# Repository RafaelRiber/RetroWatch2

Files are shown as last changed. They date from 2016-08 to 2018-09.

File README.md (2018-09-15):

# Retro|Watch 2
 <p align="center">
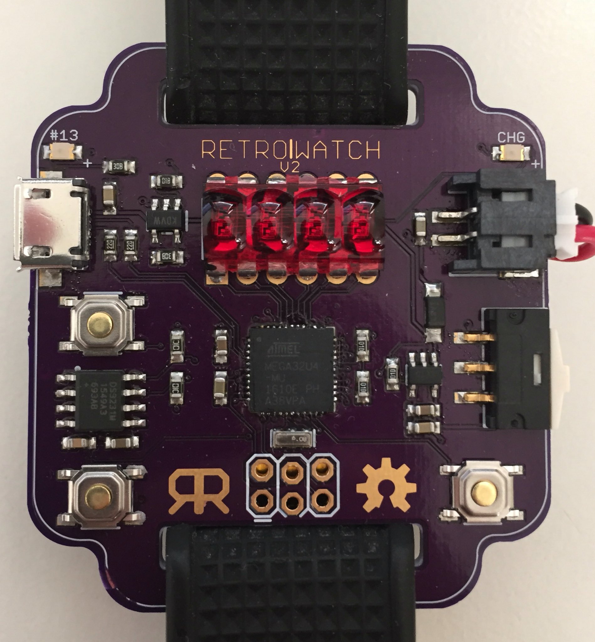
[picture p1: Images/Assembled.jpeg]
 
 <em>Assembled Board</em>
 
## Short description
The Retro|Watch V2 is based around the HP QDSP-6064 Bubble display, used in 70s HP calculators like the [HP-35](https://en.wikipedia.org/wiki/HP-35). The display is controlled by an Atmel ATMega328U4 MCU with Arduino code and flashed with an Adafruit Feather 32U4 bootloader, and the time is kept by a Maxim DS3231 Real-Time Clock module, that stays connected to the LiPo battery at all times, keeping time even when the microcontroller and display are not powered.
This second version of the watch uses another microcontroller, the ATMega32U4, for USB capability, and a battery recharge circuit for USB Charging. In order to fit all that added circuitry, smaller components as 0603 resistors and a QFN chip were used. **__THIS MAKES ASSEMBLY CONSIDERABLY HARDER THAN V1, and is not recommended for beginners.__**
The code is open source, licensed under the MIT License, and the harware is open-source hardware.

<h3>V1 was Featured on:</h3>
<p><a href="http://hackaday.com/2016/06/25/easy-bubble-watch-oozes-retro-charm/">Hackaday.com blog post by Elliot Williams</a>
<p><a href="https://blog.hackster.io/this-watch-will-spark-some-old-school-calculator-nostalgia-7b6e44203b67">Hackster.io</a>
  
## Hardware
<h3>PCB</h3>
The board design was made in Eagle, and is fully tested. A 500 mAh [LiPo Battery from Adafruit](https://adafru.it/1578) fits perfectly under the board. The board design can be freely modified. It can also directly be ordered on the OSHPark website: 
<p align="center"></p>

<h3>Bill Of Materials</h3>
You can find the BOM here: https://github.com/RafaelRiber/Retro-Watch2/blob/master/Hardware/BOM.csv
  
<h2>Software</h2>
The software was written in Arduino code, is licensed under MIT License, and can be uploaded on the microcontroller via ISP.
Be sure to set the desired time in the code prior to uploading, to set the time registers on the RTC.

Functions of the code include:
* Hours, minutes and seconds
* Day, month, year, day of year, day in week, week in year.
* Stopwatch (start, stop, reset)
* Brightness setting in software, saved to EEPROM to save even if the watch is powered off.
* Battery voltage check and low battery alert
 
To be able to upload the code on the watch, you will need to follow the same steps as V1 (see V1 repo), but using the Adafruit Feather 32U4 Bootloader instead of the ATMega328P one.
<h3>Required Libraries</h3>
<p>1. Chrono library by thomasfredericks: https://github.com/thomasfredericks/Chrono
<p>2. Button library by JChristensen: https://github.com/JChristensen/Button
<p>3. RTCLib by Adafruit Industries: https://github.com/adafruit/RTClib
<p>4. SevSeg by SparkFun: https://github.com/sparkfun/SevSeg

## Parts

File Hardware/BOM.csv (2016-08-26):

Qty | Value | Device | Package | Parts
1 | 0.1uF | C0603 | C0603 | C7
3 | 100K | R0603 | R0603 | R1 R7 R8
2 | 10K | R0603 | R0603 | R11 R12
4 | 10uF | C0603 | C0603 | C1 C2 C4 C6
1 | 1K | R0603 | R0603 | R2
3 | 1uF | C0603 | C0603 | C3 C5 C8
2 | 22R | R0603 | R0603 | R3 R4
2 | 2K | R0603 | R0603 | R5 R6
1 | 8MHz | RESONATOR SMD | RESONATOR-SMD | Y1
1 | ATMEGA32U4-MU | MCU | QFN-44 | U1
1 | DS3231M | RTC | SOIC8 | RTC1
1 | MBR120 | Schottky Diode | SOD-123 | D1
1 | MCP73831T-2ACI/OT | LiPoly Charger | SOT23-5 | U2
1 | MCS2S-A15F | SPDT Slide Switch | MCS2S-A15F | S1
1 | MIC5225-3.3YM5-TR | Voltage Regulator 3.3V | SOT23-5 | U3
1 | 10104110-0001LF | USB Connector | USB-MICROB-SMD | X2

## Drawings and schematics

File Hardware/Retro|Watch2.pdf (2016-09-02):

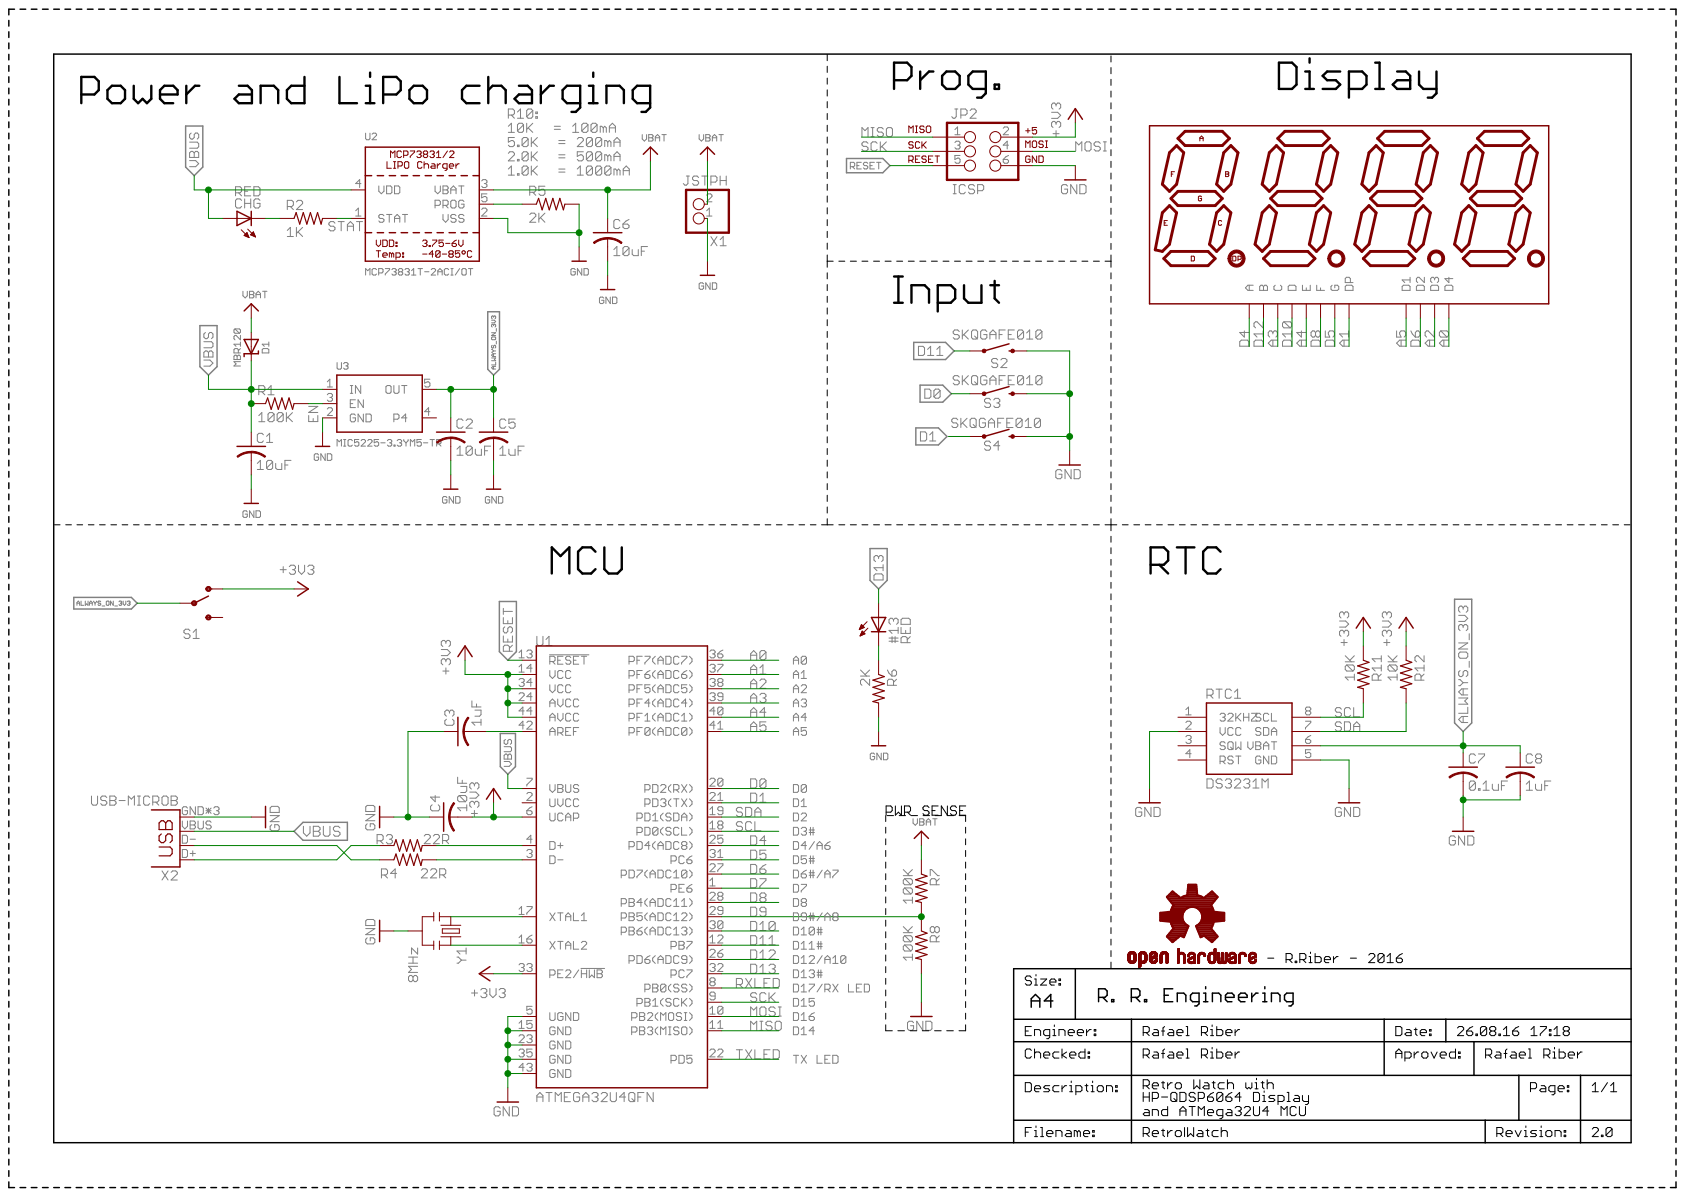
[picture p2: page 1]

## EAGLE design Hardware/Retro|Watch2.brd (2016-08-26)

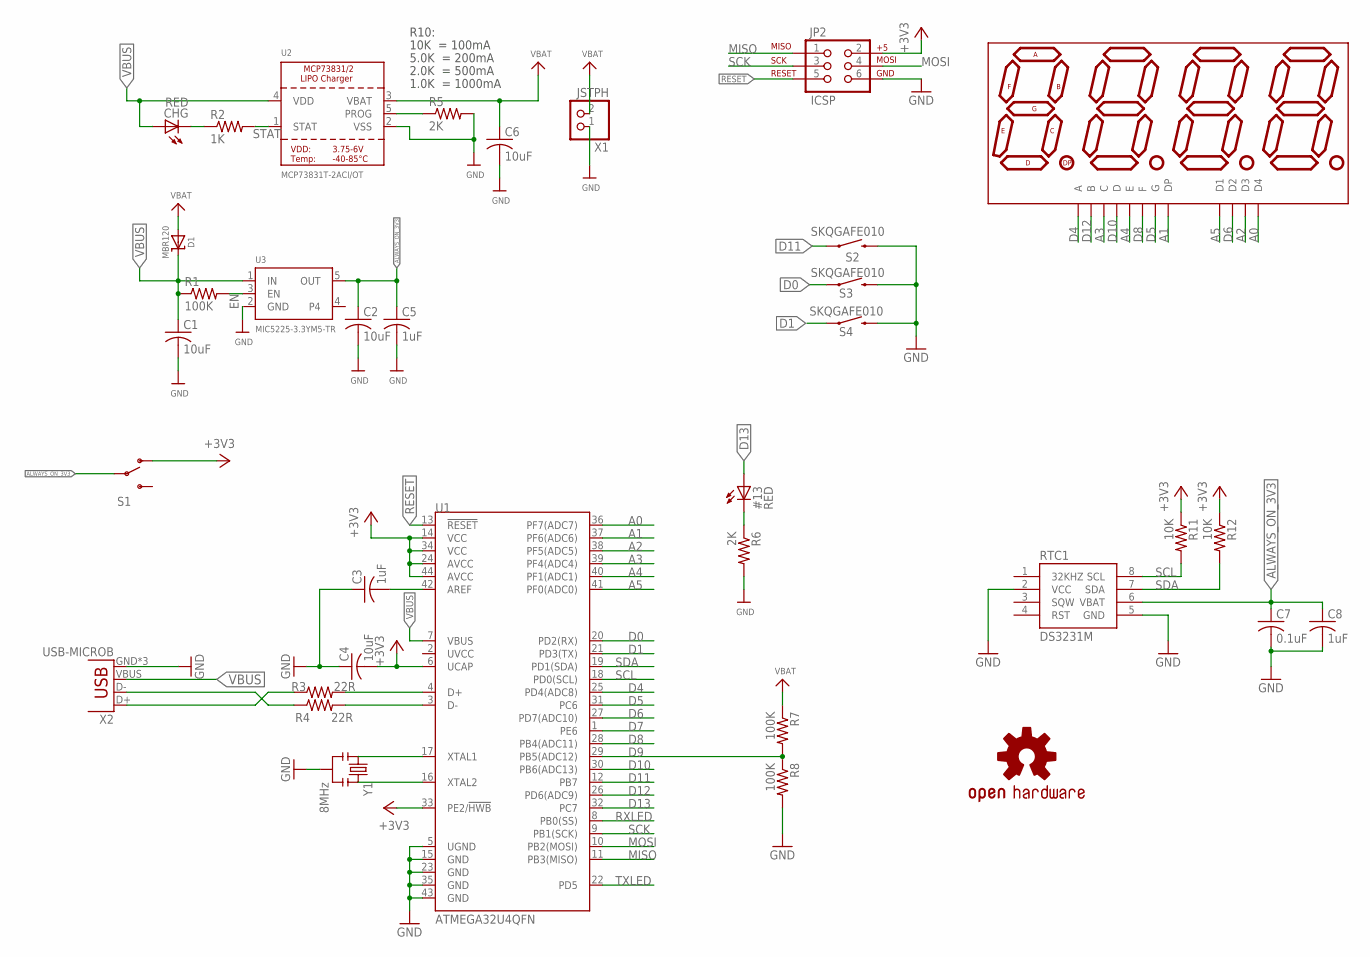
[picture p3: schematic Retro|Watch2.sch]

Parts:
#13: RED; CHIP-LED0805; MPN LGQ971
C1, C2, C6: 10uF; C0603; MPN MC0603X106M6R3CT
C3: 1uF; C0603; MPN 0805B104K500CT
C4: 10uF; C0603; MPN 0805B104K500CT
C5: 1uF; C0603; MPN CC0603MRY5V9BB104
C7: 0.1uF; C0603; MPN 0805B104K500CT
C8: 1uF; C0603; MPN 0603X105K100CT
CHG: RED; CHIP-LED0805; MPN LSQ976-Z
D1: MBR120; SOD-123; MPN MBR120VLSFT1G
DISP1: hp; DIL12
JP2: ICSP; 2X3_LOCK
LOGO1: OSHW-LOGOM-COPPER; OSHW-LOGO-M_COPPER
R1, R7, R8: 100K; R0603; MPN CRCW0603100KFKEA.
R2: 1K; R0603; MPN MC0063W06031221R
R3, R4: 22R; R0603; MPN CRCW060322R0FKEA
R5: 2K; R0603; MPN CRCW060310K0JNEA
R6: 2K; R0603; MPN CRCW06032K20JNEA
R11, R12: 10K; R0603; MPN CRCW060310K0FKEA
RTC1: DS3231M; SOIC8; MPN DS3231MZ+TRL
S1: SWITCH-SPDTSMD2; SWITCH-SPDT-SMD
S2, S3, S4: SKQGAFE010; TACTILE-SWITCH-SMD; MPN SKQGAFE010
U1: ATMEGA32U4QFN; QFN-44; MPN ATMEGA32U4-MU
U2: MCP73831T-2ACI/OT; SOT23-5@1; MPN MCP73831T-2ACI/OT
U3: MIC5225-3.3YM5-TR; SOT23-5; MPN MIC5225-3.3YM5-TR
X1: JSTPH; JSTPH2; MPN S2B-PH-SM4-TB(LF)(SN)
X2: USB-MICROB; MPN 10104110-0001LF
Y1: 8MHz; RESONATOR-SMD

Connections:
+3V3: C4.2, JP2.2, R11.1, R12.1, S1.1 (O), U1.6 (UCAP), U1.14 (VCC), U1.24 (AVCC), U1.33 (PE2/!HWB), U1.34 (VCC), U1.44 (AVCC)
A0: DISP1.6 (D4), U1.36 (PF7(ADC7))
A1: DISP1.5 (DP), U1.37 (PF6(ADC6))
A2: DISP1.4 (D3), U1.38 (PF5(ADC5))
A3: DISP1.3 (C), U1.39 (PF4(ADC4))
A4: DISP1.2 (E), U1.40 (PF1(ADC1))
A5: DISP1.1 (D1), U1.41 (PF0(ADC0))
ALWAYS_ON_3V3: C2.1, C5.1, C7.1, C8.1, RTC1.6 (VBAT), S1.2, U3.5 (OUT)
AREF: C3.2, U1.42 (AREF)
D0: S3.1, U1.20 (PD2(RX))
D1: S4.1, U1.21 (PD3(TX))
D4: DISP1.12 (A), U1.25 (PD4(ADC8))
D5: DISP1.7 (G), U1.31 (PC6)
D6: DISP1.10 (D2), U1.27 (PD7(ADC10))
D7: U1.1 (PE6)
D8: DISP1.9 (F), U1.28 (PB4(ADC11))
D9: R7.2, R8.1, U1.29 (PB5(ADC12))
D10: DISP1.8 (D), U1.30 (PB6(ADC13))
D11: S2.1, U1.12 (PB7)
D12: DISP1.11 (B), U1.26 (PD6(ADC9))
D13: #13.A, U1.32 (PC7)
D+: R3.1, X2.D+
D-: R4.1, X2.D-
EN: R1.2, U3.3 (EN)
GND: C1.2, C2.2, C3.1, C4.1, C5.2, C6.2, C7.2, C8.2, JP2.6, R5.2, R6.2, R8.2, RTC1.2 (VCC), RTC1.5 (GND), S2.3 (2), S3.3 (2), S4.3 (2), U1.5 (UGND), U1.15 (GND), U1.23 (GND), U1.35 (GND), U1.43 (GND), U2.2 (VSS), U3.2 (GND), X1.1, X2.GND, X2.MT1 (GND), X2.MT2 (GND), Y1.2
MISO: JP2.1, U1.11 (PB3(MISO))
MOSI: JP2.4, U1.10 (PB2(MOSI))
unnamed: U1.17 (XTAL1), Y1.1
unnamed: U1.16 (XTAL2), Y1.3
unnamed: R3.2, U1.4 (D+)
unnamed: R4.2, U1.3 (D-)
unnamed: CHG.C, R2.1
unnamed: #13.C, R6.1
PROG: R5.1, U2.5 (PROG)
RESET: JP2.5, U1.13 (!RESET)
RXLED: U1.8 (PB0(SS))
SCK: JP2.3, U1.9 (PB1(SCK))
SCL: R11.2, RTC1.8 (SCL), U1.18 (PD0(SCL))
SDA: R12.2, RTC1.7 (SDA), U1.19 (PD1(SDA))
STAT: R2.2, U2.1 (STAT)
TXLED: U1.22 (PD5)
VBAT: C6.1, D1.A, R7.1, U2.3 (VBAT), X1.2
VBUS: C1.1, CHG.A, D1.C, R1.1, U1.7 (VBUS), U2.4 (VDD), U3.1 (IN), X2.VBUS

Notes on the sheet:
10K = 100mA
5.0K = 200mA
2.0K = 500mA
1.0K = 1000mA
R10:

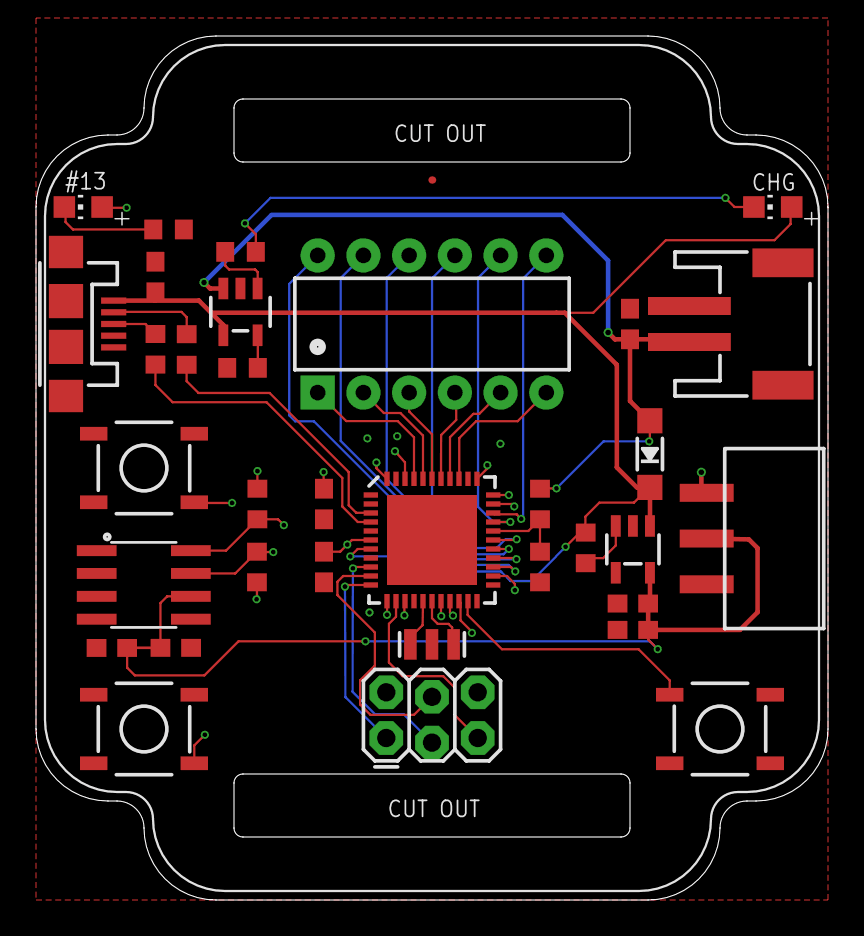
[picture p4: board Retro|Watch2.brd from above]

Board: 4 copper layers, 44.0 x 48.0 mm, 35 parts (0 on the bottom side), 40 nets.

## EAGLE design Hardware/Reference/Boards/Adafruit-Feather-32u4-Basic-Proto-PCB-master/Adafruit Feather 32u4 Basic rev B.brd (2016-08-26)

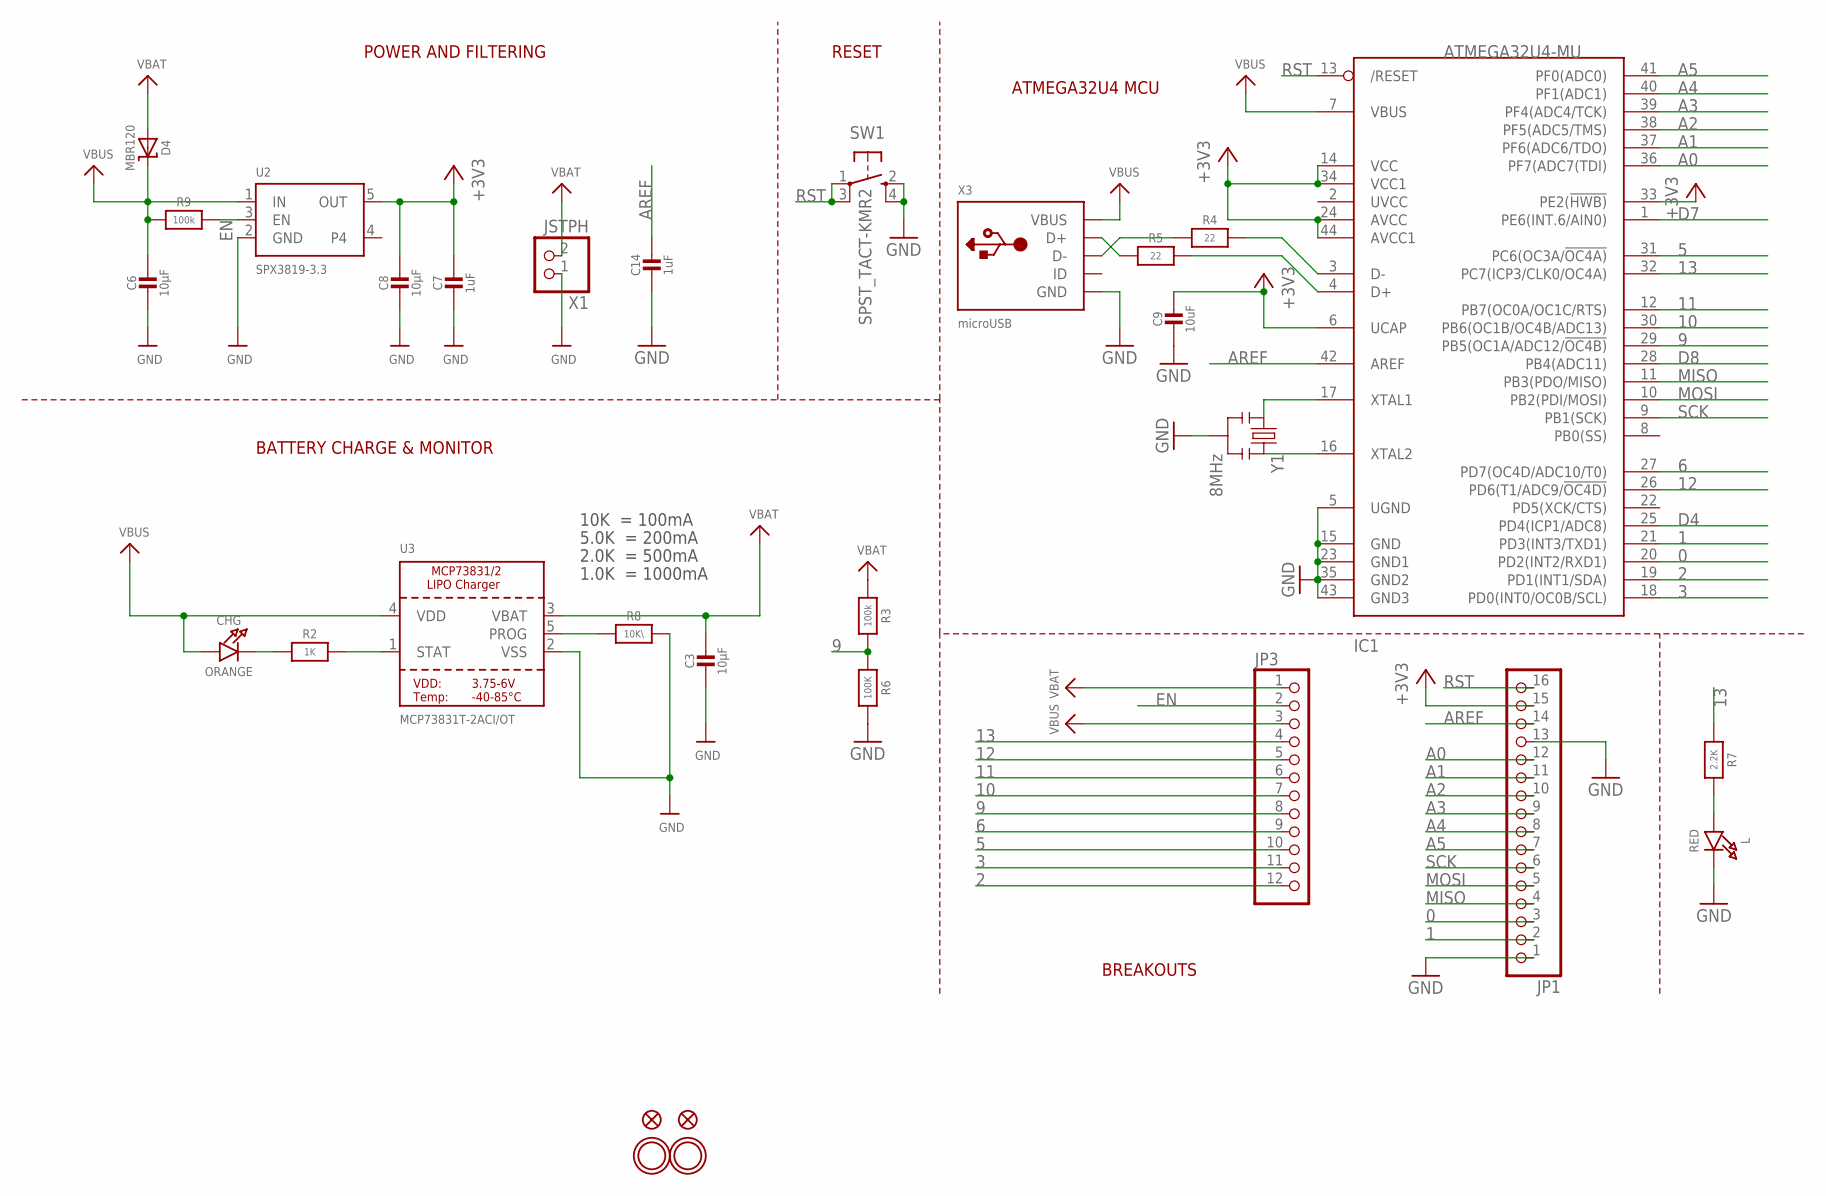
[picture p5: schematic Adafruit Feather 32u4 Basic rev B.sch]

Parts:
C3, C6, C8: 10µF; 0805-NO
C7, C14: 1uF; 0603-NO
C9: 10uF; 0805-NO
CHG: ORANGE; CHIPLED_0805_NOOUTLINE
D4: MBR120; SOD-123
IC1: ATMEGA32U4-MU; TQFN44_7MM
JP1: HEADER-1X16ROUND; 1X16_ROUND
JP3: HEADER-1X12; 1X12_ROUND
L: RED; CHIPLED_0805_NOOUTLINE
R2: 1K; 0603-NO
R3, R9: 100k; 0603-NO
R4, R5: 22; 0603-NO
R6: 100K; _0603MP
R7: 2.2K; 0603-NO
R8: 10K\; 0603-NO
SW1: SPST_TACT-KMR2; KMR2
U2: SPX3819-3.3; SOT23-5
U3: MCP73831T-2ACI/OT; SOT23-5
U$31, U$32: MOUNTINGHOLE2.5; MOUNTINGHOLE_2.5_PLATED
U$34, U$35: FIDUCIAL""; FIDUCIAL_1MM
X1: JSTPH; JSTPH2
X3: microUSB; 4UCONN_20329_V2
Y1: 8MHz; RESONATOR-SMD

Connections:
0: IC1.20 (PD2(INT2/RXD1)), JP1.3
1: IC1.21 (PD3(INT3/TXD1)), JP1.2
2: IC1.19 (PD1(INT1/SDA)), JP3.12
3: IC1.18 (PD0(INT0/OC0B/SCL)), JP3.11
5: IC1.31 (PC6(OC3A/!OC4A)), JP3.10
6: IC1.27 (PD7(OC4D/ADC10/T0)), JP3.9
9: IC1.29 (PB5(OC1A/ADC12/!OC4B)), JP3.8, R3.2, R6.1
10: IC1.30 (PB6(OC1B/OC4B/ADC13)), JP3.7
11: IC1.12 (PB7(OC0A/OC1C/RTS)), JP3.6
12: IC1.26 (PD6(T1/ADC9/!OC4D)), JP3.5
13: IC1.32 (PC7(ICP3/CLK0/OC4A)), JP3.4, R7.1
+3V3: C7.1, C8.1, C9.1, IC1.6 (UCAP), IC1.14 (VCC), IC1.24 (AVCC), IC1.33 (PE2(!HWB)), IC1.34 (VCC1), IC1.44 (AVCC1), JP1.15, U2.5 (OUT)
A0: IC1.36 (PF7(ADC7(TDI)), JP1.12
A1: IC1.37 (PF6(ADC6/TDO)), JP1.11
A2: IC1.38 (PF5(ADC5/TMS)), JP1.10
A3: IC1.39 (PF4(ADC4/TCK)), JP1.9
A4: IC1.40 (PF1(ADC1)), JP1.8
A5: IC1.41 (PF0(ADC0)), JP1.7
AREF: C14.1, IC1.42 (AREF), JP1.14
D4: IC1.25 (PD4(ICP1/ADC8))
D7: IC1.1 (PE6(INT.6/AIN0))
D8: IC1.28 (PB4(ADC11))
D+: IC1.4 (D+), R5.2
D-: IC1.3 (D-), R4.2
EN: JP3.2, R9.2, U2.3 (EN)
GND: C3.2, C6.2, C7.2, C8.2, C9.2, C14.2, IC1.5 (UGND), IC1.15 (GND), IC1.23 (GND1), IC1.35 (GND2), IC1.43 (GND3), JP1.1, JP1.13, L.C, R6.2, R8.2, SW1.2 (S), SW1.4 (S1), U2.2 (GND), U3.2 (VSS), X1.1, X3.BASE@1 (GND), X3.BASE@2 (GND), X3.GND, X3.SPRT@1 (GND), X3.SPRT@2 (GND), X3.SPRT@3 (GND), X3.SPRT@4 (GND), Y1.2
MISO: IC1.11 (PB3(PDO/MISO)), JP1.4
MOSI: IC1.10 (PB2(PDI/MOSI)), JP1.5
unnamed: CHG.C, R2.1
unnamed: L.A, R7.2
unnamed: R2.2, U3.1 (STAT)
unnamed: R8.1, U3.5 (PROG)
unnamed: IC1.16 (XTAL2), Y1.3
unnamed: IC1.17 (XTAL1), Y1.1
unnamed: R5.1, X3.D+
unnamed: R4.1, X3.D-
RST: IC1.13 (/RESET), JP1.16, SW1.1, SW1.3 (P1)
SCK: IC1.9 (PB1(SCK)), JP1.6
VBAT: C3.1, D4.A, JP3.1, R3.1, U3.3 (VBAT), X1.2
VBUS: C6.1, CHG.A, D4.C, IC1.7 (VBUS), JP3.3, R9.1, U2.1 (IN), U3.4 (VDD), X3.VBUS

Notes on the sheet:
POWER AND FILTERING
RESET
ATMEGA32U4 MCU
10K = 100mA
5.0K = 200mA
2.0K = 500mA
1.0K = 1000mA
BATTERY CHARGE & MONITOR
BREAKOUTS

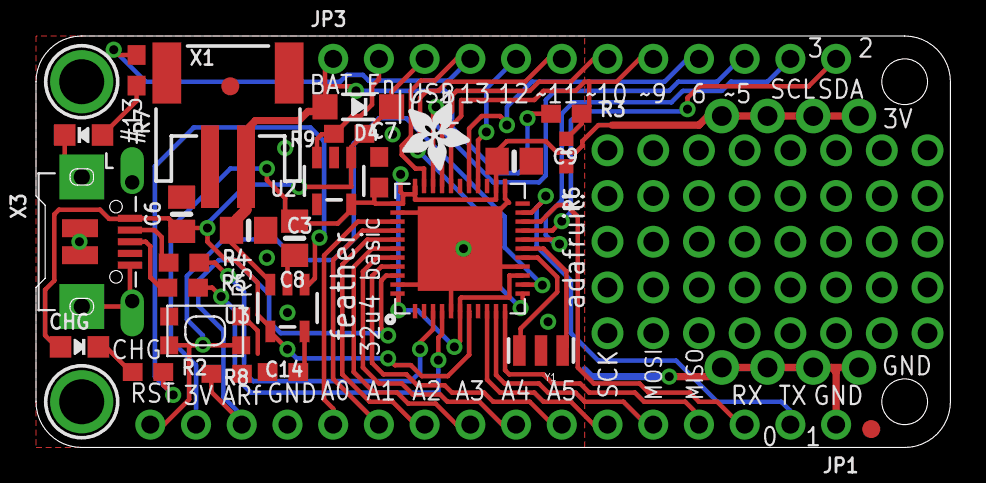
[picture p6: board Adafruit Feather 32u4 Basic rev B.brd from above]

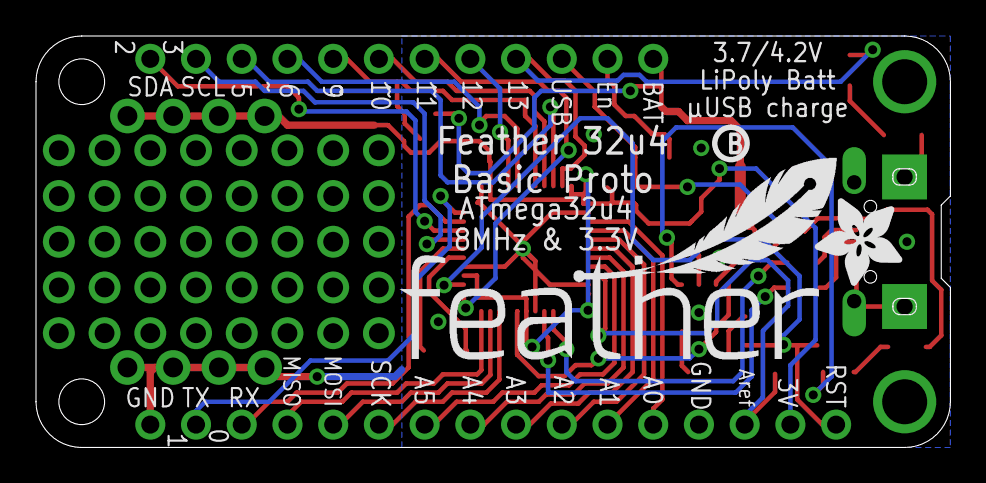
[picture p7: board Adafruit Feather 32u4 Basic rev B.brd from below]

Board: 2 copper layers, 50.8 x 22.9 mm, 34 parts (3 on the bottom side), 37 nets.

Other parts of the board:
U$4: ADAFRUIT_5MM
U$5: FEATHERLOGO
U$6: PCBFEAT-REV-040
U$7: ADAFRUIT_3.5MM

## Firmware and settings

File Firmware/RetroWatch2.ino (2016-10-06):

/**
  The MIT License (MIT)

  Copyright (c) 2016 Rafael Riber

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
  THE SOFTWARE IS PROVIDED "AS IS", WITHOUT WARRANTY OF ANY KIND, EXPRESS OR
  IMPLIED, INCLUDING BUT NOT LIMITED TO THE WARRANTIES OF MERCHANTABILITY,
  FITNESS FOR A PARTICULAR PURPOSE AND NONINFRINGEMENT. IN NO EVENT SHALL THE
  AUTHORS OR COPYRIGHT HOLDERS BE LIABLE FOR ANY CLAIM, DAMAGES OR OTHER
  LIABILITY, WHETHER IN AN ACTION OF CONTRACT, TORT OR OTHERWISE, ARISING FROM,
  OUT OF OR IN CONNECTION WITH THE SOFTWARE OR THE USE OR OTHER DEALINGS IN THE
  SOFTWARE.
**/

//Include required libraries
#include <Chrono.h>
#include <LightChrono.h>
#include <RTClib.h>
#include <Wire.h>
#include <SevSeg.h>
#include <EEPROM.h>
#include <Button.h>

//Define constants
#define BUTTON1 11
#define VBATPIN A9
#define BUTTON2 0
#define BUTTON3 1

//Init objects
Button button1(BUTTON1, true,  true, 25);
Button button2(BUTTON2, true,  true, 25);
Button button3(BUTTON3, true,  true, 25);
SevSeg sevSeg;
RTC_DS3231 rtc;

Chrono myChrono(Chrono::SECONDS);

//Declare vars
byte temp_msb;
byte temp_lsb;
unsigned long timer;
unsigned int seconds;
unsigned int minutes;
unsigned int hours;
unsigned int months;
unsigned int days;
unsigned int year;
unsigned int doy;
unsigned int dow;
unsigned int woy;
unsigned int time_show;
unsigned long display_time;
unsigned long display_date;
unsigned long deciSecond;
int count = 1;
int addr = 0;
int menu;
int mode;
int watch;
int brightness;
int date;
int vbat;
float measuredvbat;

//Get seconds from RTC
unsigned int get_seconds()
{
  DateTime now = rtc.now();
  seconds = now.second();
  return seconds;
}

//Get minutes from RTC
unsigned int get_minutes()
{
  DateTime now = rtc.now();
  minutes = now.minute();
  return minutes;
}

//Get hours from RTC
unsigned int get_hours()
{
  DateTime now = rtc.now();
  hours = now.hour();
  return hours;
}

//Get days from RTC
unsigned int get_days()
{
  DateTime now = rtc.now();
  days = now.day();

  return days;
}

//Get months from RTC
unsigned int get_months()
{
  DateTime now = rtc.now();
  months = now.month();
  return months;
}

//Get year from RTC
unsigned int get_year()
{
  DateTime now = rtc.now();
  year = now.year();
  return year;
}

unsigned int get_doy()
{
  DateTime now = rtc.now();
  doy = now.dayOfYear();
  return doy;
}

unsigned int get_dow()
{
  DateTime now = rtc.now();
  dow = now.dayOfTheWeek();
  return dow;
}

//Show hours and minutes on display
void show_hm()
{
  get_seconds();
  get_minutes();
  get_hours();

  display_time = (hours * 100) + minutes;

  char tempString[5];
  sprintf(tempString, "%04d", display_time);
  sevSeg.DisplayString(tempString, 2);
}

//Show minutes and seconds on display
void show_ms()
{
  get_seconds();
  get_minutes();
  get_hours();

  display_time = (minutes * 100) + seconds;

  char tempString[5];
  sprintf(tempString, "%04d", display_time);
  sevSeg.DisplayString(tempString, 2);
}

//Show date on display
void show_date()
{
  char tempString[5];
  switch (date)
  {
    case 0:
      get_days();
      get_months();
      display_date = (days * 100) + months;
      sprintf(tempString, "%04d", display_date);
      sevSeg.DisplayString(tempString, 2);
      break;
    case 1:
      get_year();
      sprintf(tempString, "%4d", year);
      sevSeg.DisplayString(tempString, 0);
      break;
    case 2:
      get_doy();
      sprintf(tempString, "%4d", doy);
      sevSeg.DisplayString(tempString, 0);
      break;
    case 3:
      get_dow();
      sprintf(tempString, "%4d", dow);
      sevSeg.DisplayString(tempString, 0);
      break;
    case 4:
      get_doy();
      woy = doy / 7;
      sprintf(tempString, "%4d", woy);
      sevSeg.DisplayString(tempString, 0);
  }
  if (button2.wasPressed())
  {
    date = date - 1;
  }
  if (button3.wasPressed())
  {
    date++;
  }
  if (date < 0)
  {
    date = 4;
  }
  if (date > 4)
  {
    date = 0;
  }
}

//Stopwatch function
void stopwatch()
{
  switch (count)
  {
    case 0:
      char tempString[5];
      if (myChrono.hasPassed(1))
      {
        deciSecond++;
        sprintf(tempString, "%04d", deciSecond);
        if (deciSecond < 10000)
        {
          sevSeg.DisplayString(tempString, 2);
        }
        if (deciSecond >= 10000)
        {
          sevSeg.DisplayString(tempString, 4);
        }
      }
      break;
    case 1:
      sprintf(tempString, "%04d", deciSecond);
      if (deciSecond < 10000)
      {
        sevSeg.DisplayString(tempString, 2);
      }
      if (deciSecond >= 10000)
      {
        sevSeg.DisplayString(tempString, 4);
      }
      break;
  }
  if (button3.wasPressed())
  {
    if (count <= 1)
    {
      count++;
    }
    if (count > 1)
    {
      count = 0;
    }
  }
  if (button2.wasPressed())
  {
    deciSecond = 0;
  }
}


void time()
{
  switch (time_show)
  {
    case 0:
      show_hm();
      break;
    case 1:
      show_ms();
      break;
  }
  if (button2.wasPressed())
  {
    time_show = time_show - 1;
  }
  if (button3.wasPressed())
  {
    time_show++;
  }
  if (time_show < 0)
  {
    time_show = 1;
  }
  if (time_show > 1)
  {
    time_show = 0;
  }
}

//Set brightness and save to EEPROM if different than before
void brightness_set()
{
  char tempString[5];
  sprintf(tempString, "%4d", brightness);
  sevSeg.DisplayString(tempString, 0);

  if (button2.wasPressed())
  {
    brightness = brightness - 1;
  }
  if (button3.wasPressed())
  {
    brightness = brightness + 1;
  }
  if (brightness > 10)
  {
    brightness = 10;
  }
  if (brightness < 0)
  {
    brightness = 0;
  }
  if (button1.wasPressed())
  {
    //Save brightness to EEPROM
    if (brightness != EEPROM.read(0))
    {
      EEPROM.write(0, brightness);
    }
    mode = 3;
    watch = 0;
  }
}

void batt_show()
{
  float measuredvbat = analogRead(VBATPIN);
  measuredvbat *= 2;    // we divided by 2, so multiply back
  measuredvbat *= 3.3;  // Multiply by 3.3V, our reference voltage
  measuredvbat /= 1024; // convert to voltage

  vbat = measuredvbat * 100;
  char tempString[5];
  sprintf(tempString, "%4d", vbat);
  sevSeg.DisplayString(tempString, 2);
}

void batt_check()
{
  float measuredvbat = analogRead(VBATPIN);
  measuredvbat *= 2;    // we divided by 2, so multiply back
  measuredvbat *= 3.3;  // Multiply by 3.3V, our reference voltage
  measuredvbat /= 1024; // convert to voltage

  if (measuredvbat < 3.6)
  {
    watch = 2;
  }
  if (button1.wasPressed())
  {
    watch = 0;
  }
}

//Mode selection menu
void menu_select()
{
  switch (menu)
  {
    case 0:
      sevSeg.DisplayString("Hour", 0);
      if (button1.wasPressed())
      {
        mode = 0;
        watch = 0;
      }
      break;
    case 1:
      sevSeg.DisplayString("Date", 0);
      if (button1.wasPressed())
      {
        mode = 1;
        watch = 0;
      }
      break;
    case 2:
      sevSeg.DisplayString("Chro", 0);
      if (button1.wasPressed())
      {
        mode = 2;
        watch = 0;
      }
      break;
    case 3:
      sevSeg.DisplayString("Brtx", 0);
      if (button1.wasPressed())
      {
        mode = 3;
        watch = 0;
      }
      break;
    case 4:
      sevSeg.DisplayString("Batt", 0);
      if (button1.wasPressed())
      {
        mode = 4;
        watch = 0;
      }
      break;
  }

  if (button2.wasPressed())
  {
    menu = menu - 1;
  }
  if (button3.wasPressed())
  {
    menu++;
  }
  if (menu < 0)
  {
    menu = 0;
  }
  if (menu > 4)
  {
    menu = 4;
  }
}

//Modes
void modes()
{
  switch (mode)
  {
    case 0:
      time();
      break;
    case 1:
      show_date();
      break;
    case 2:
      stopwatch();
      break;
    case 3:
      brightness_set();
      break;
    case 4:
      batt_show();
      break;
  }
  if (button1.wasPressed())
  {
    watch++;
    if (watch > 1)
    {
      watch = 0;
    }
  }
  if (mode < 0)
  {
    mode = 0;
  }
  if (mode > 4)
  {
    mode = 4;
  }
}

//Initial setup
void setup()
{
  delay(10);
  rtc.begin();
  timer = millis();
  pinMode(9, INPUT);

  //Set time if RTC lost power
  if (rtc.lostPower())
  {
    // The following line sets the RTC to the date & time this sketch was compiled
    //rtc.adjust(DateTime(F(__DATE__), F(__TIME__)));
    // This line sets the RTC with an explicit date & time:
    rtc.adjust(DateTime(2016, 10, 2, 18, 35, 0));
  }
  //Init display vars
  int displayType = COMMON_CATHODE;

  int digit1 = A5;
  int digit2 = 6;
  int digit3 = A2;
  int digit4 = A0;

  int segA = 4;
  int segB = 12;
  int segC = A3;
  int segD = 10;
  int segE = A4;
  int segF = 8;
  int segG = 5;
  int segDP = A1;

  int numberOfDigits = 4;

  sevSeg.Begin(displayType, numberOfDigits, digit1, digit2, digit3, digit4, segA, segB, segC, segD, segE, segF, segG, segDP);
  brightness = EEPROM.read(0);
  batt_check();
}

//Main loop
void loop()
{
  button1.read();
  button2.read();
  button3.read();
  sevSeg.SetBrightness(brightness * 10);
  switch (watch)
  {
    case 0:
      modes();
      break;
    case 1:
      menu_select();
      break;
    case 2:
      for (int i; i < 100; i++)
      {
        sevSeg.DisplayString("BATL", 0);
      }
      watch = 0;
      break;
  }
}

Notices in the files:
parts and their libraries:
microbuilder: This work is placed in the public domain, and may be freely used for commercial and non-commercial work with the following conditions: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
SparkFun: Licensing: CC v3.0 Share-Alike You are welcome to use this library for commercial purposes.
